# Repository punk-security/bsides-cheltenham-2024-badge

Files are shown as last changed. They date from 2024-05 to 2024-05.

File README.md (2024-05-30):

# bsides-cheltenham-2024-badge
The UFO badge for BSIDES Cheltenham 2024!

Lots of things in this repo:

- eagle-files: all the stuff you need to tinker and modify the PCB
- gerber-files.zip: the file you can upload to JLCPCB and order your own badge, as is
- 3d_printed_case.stl: a cool little push fit case you can print
- bsides-cheltenham-2024-badge.ino: the arduino code that powers the badge, which you can modify and flash via the SAO connector
- ufo.svg: the original vector design for the badge
- morse_code_instructional_booklet.pdf: the flyer we gave out on the day with the codes and instructions

## Bill Of Materials

You can see a parts list on DigiKey [here](https://www.digikey.co.uk/en/mylists/list/Z9CH9C1GM3)

Essentially its:

* ATTINY402 microcontroller 
* Button - any surface mount button fitting the footprint will work
* CR2032 battery clip - surface mount not through hole
* Neopixel 5050 addressable LED - Definitely get the right version of these

## Eagle designs and ordering your own badge

We've uploaded the AutoCAD EAGLE schematic, board design and custom footprints so you can make your own variants!  You will probably have to do some tweaks to get it working as they're not designed to be standalone exports.

We've also uploaded the gerber_files.zip.  Take this to JLCPCB and you can order your own exact copies of the board :)

## Writing and flashing code!

We use [MegaTinyCore](https://github.com/SpenceKonde/megaTinyCore) for the arduino interface for ATTINY4x2 chips.

Dev and flashing is done within the Arduino IDE ( < v2 ) using a jtag2updi interface, as discussed [here](https://github.com/SpenceKonde/AVR-Guidance/blob/master/UPDI/jtag2updi.md)

We use [these little usb sticks](https://amzn.eu/d/c0lx0wG), with a 4.7k resistor soldered between the Tx and Rx lines.  

### Installing MegaTinyCore dependencies

This board package can be installed via the board manager in arduino. The boards manager URL is:

`http://drazzy.com/package_drazzy.com_index.json`

1. File -> Preferences, enter the above URL in "Additional Boards Manager URLs"
2. Tools -> Boards -> Boards Manager...
3. Wait while the list loads (takes longer than one would expect, and refreshes several times).
4. Select "megaTinyCore by Spence Konde" and click "Install". For best results, choose the most recent version.

### Setting up the IDE

1. Open the file **bsides-cheltenham-2024-badge.ino** in arduino
2. Select tools > Board > megaTinyCore > ATtiny412/402/212/202
3. Select tools > Chip > ATtiny402
4. Select tools > Clock > 8Mhz internal *(we get power issues otherwise)*
5. Select tools > Programmer > SerialUPDI SLOW
6. Select tools > Port > ( pick your COM port)

### Flashing firmware
1. Connect the 3v3 pin to 3v on your usb (maybe wedge it in the battery clip)
2. Connect GND to GND
3. Connect UPDI to the RxD port
4. Click Upload button

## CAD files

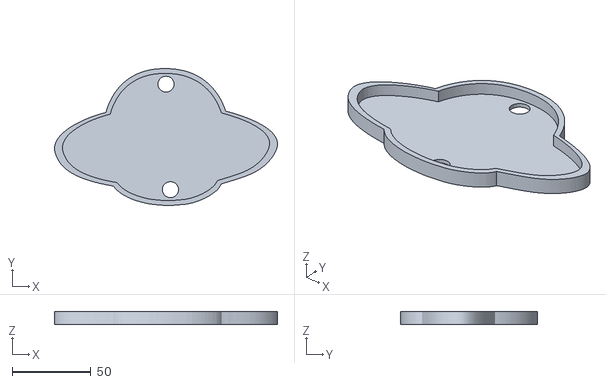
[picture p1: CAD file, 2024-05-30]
3d_printed_case.stl
142.0 x 87.2 x 8.00

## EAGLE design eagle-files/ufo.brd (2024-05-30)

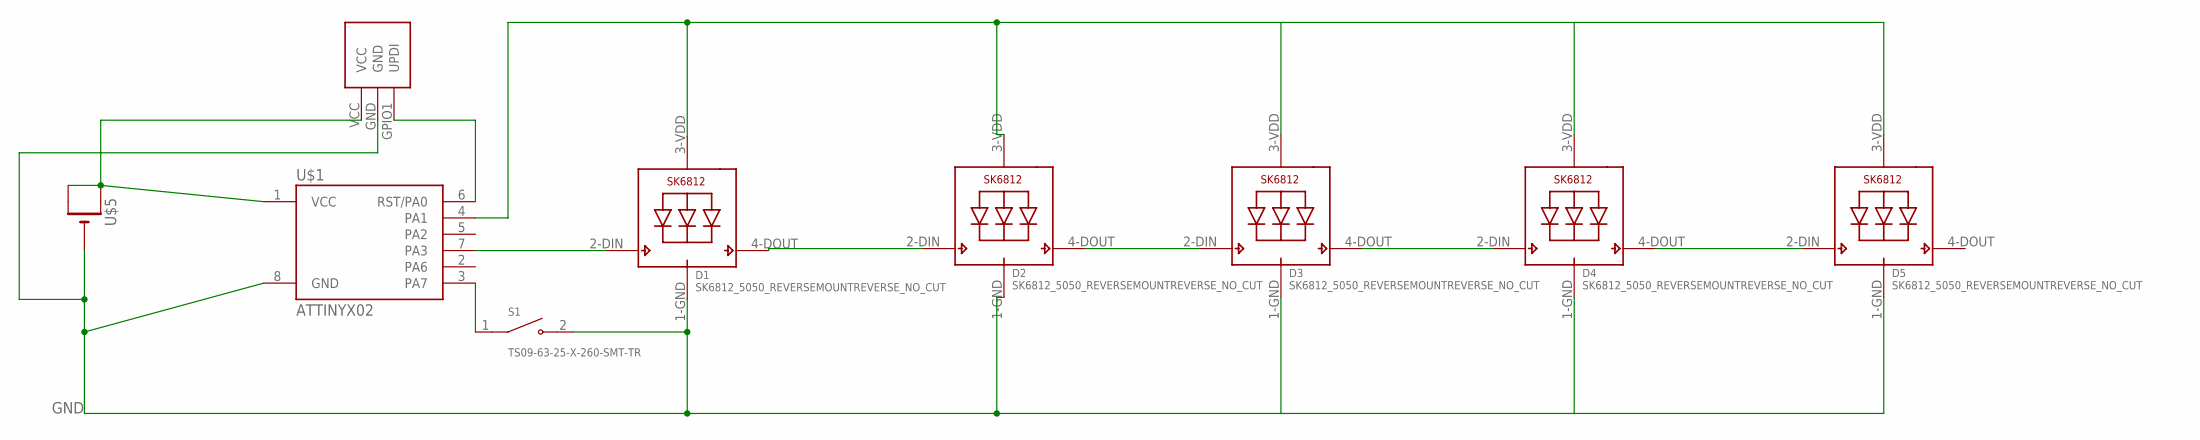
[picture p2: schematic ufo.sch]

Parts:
D1, D2, D3, D4, D5: SK6812_5050_REVERSEMOUNTREVERSE_NO_CUT; SK6812_REVERSE_NO_CUT
S1: TS09-63-25-X-260-SMT-TR; SW_TS09-63-25-X-260-SMT-TR
U$1: ATTINYX02; SOIC08_JEDEC_150MIL
U$2: SAO; SAO_SMD
U$5: CR2032SMT; CR2032-SMD

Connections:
GND: D1.1-GND (GND), D2.1-GND (GND), D3.1-GND (GND), D4.1-GND (GND), D5.1-GND (GND), S1.2, U$1.8 (GND), U$2.GND, U$5.-
unnamed: D1.4-DOUT (DO), D2.2-DIN (DI)
unnamed: D1.2-DIN (DI), U$1.7 (PA3)
unnamed: D3.4-DOUT (DO), D4.2-DIN (DI)
unnamed: D2.4-DOUT (DO), D3.2-DIN (DI)
unnamed: S1.1, U$1.3 (PA7)
unnamed: D4.4-DOUT (DO), D5.2-DIN (DI)
unnamed: U$1.6 (RST/PA0), U$2.GPIO1 (UPDI)
VCC1: U$1.1 (VCC), U$2.VCC, U$5.+$1 (+), U$5.+$2 (+1)
VDD1: D1.3-VDD (VDD), D2.3-VDD (VDD), D3.3-VDD (VDD), D4.3-VDD (VDD), D5.3-VDD (VDD), U$1.4 (PA1)

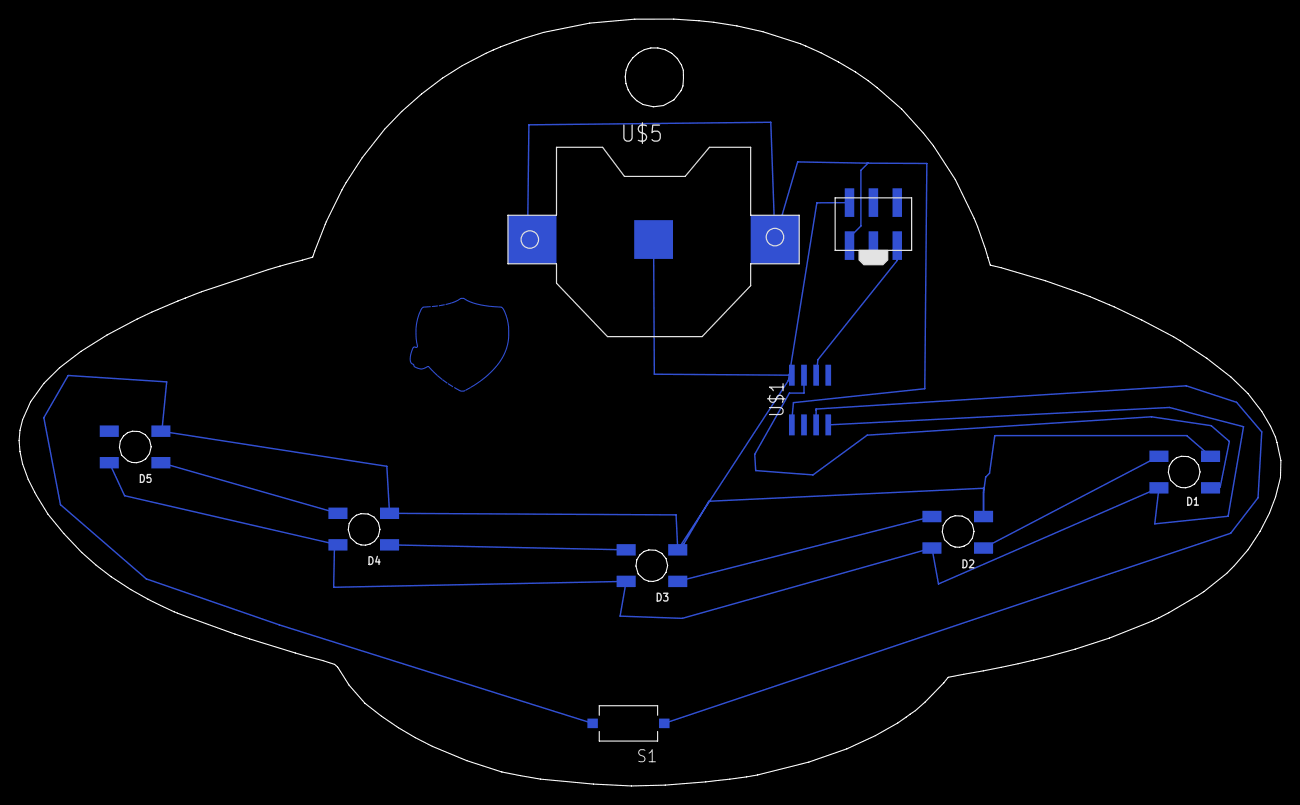
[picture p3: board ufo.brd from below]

Board: 2 copper layers, 132.1 x 80.3 mm, 9 parts (9 on the bottom side), 10 nets.

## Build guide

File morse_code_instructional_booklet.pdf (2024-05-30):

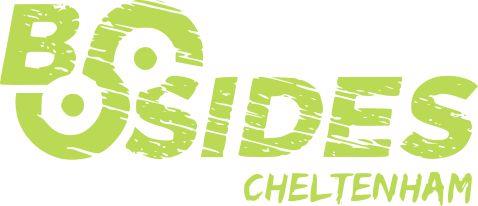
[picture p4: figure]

# Instructions:

⏱️ Short press to change mode
🔐 To unlock a new mode:
> HOLD button until solid blue
> Enter morse code sequence
> Green means good, Red is a fail

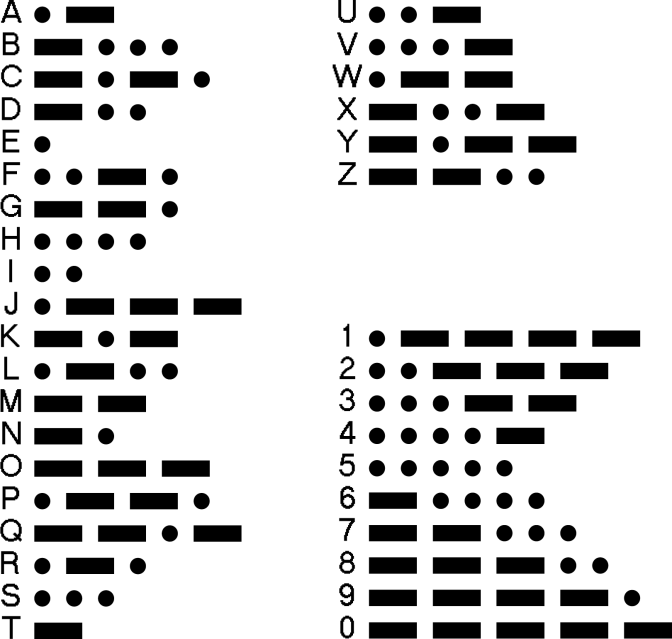
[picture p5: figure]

‼️ TIP: Morse code is time sensitive, leave a small pause between each letter / number.

# Unlock codes:

### > RGB > SOS > 1JUN > UFO > CISO > SEC > PUNK

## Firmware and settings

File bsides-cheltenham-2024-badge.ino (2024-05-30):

#include <avr/io.h>-
#include <avr/pgmspace.h>
#include <avr/sleep.h>
#include <EEPROM.h>
#include <tinyNeoPixel_Static.h>


// PINS
#define MORSE_CODE_PIN PIN_PA7

// COLOURS
#define OFF 0,0,0
#define RED 50,0,0
#define ORANGE 40,10,0
#define YELLOW 30,20,0
#define GREEN 0,50,0
#define BLUE 0,0,50
#define PURPLE 10,0,20
#define PINK 20,0,10



// MORSE CODE
/*
 *
 * MORSE CODE is between 1 and 5 pulses long
 *
 * To store this in one byte we have the length, (3 bits) and each position as either 0 (dot) or 1 (dash)
 * i.e.
 * A = 010 01 000
 * B = 100 1000 0
 * C = 100 1010 0
 */
// A .-
#define m_A B01001000
// B -...
#define m_B B10010000
// C -.-.
#define m_C B10010100
// D -..
#define m_D B01110000
// E .
#define m_E B00100000
// F ..-.
#define m_F B10000100
// G --.
#define m_G B01111000
// H ....
#define m_H B10000000
// I ..
#define m_I B01000000
// J .---
#define m_J B10001110
// K -.-
#define m_K B01110100
// L .-..
#define m_L B10001000
// M --
#define m_M B01011000
// N -.
#define m_N B01010000
// O ---
#define m_O B01111100
// P .--.
#define m_P B10001100
// Q --.-
#define m_Q B10011010
// R .-.
#define m_R B01101000
// S ...
#define m_S B01100000
// T -
#define m_T B00110000
// U ..-
#define m_U B01100100
// V ...-
#define m_V B10000010
// W .--
#define m_W B01101100
// X -..-
#define m_X B10010010
// Y -.--
#define m_Y B10010110
// Z --..
#define m_Z B10011000
// 1 .----
#define m_1 B10101111
// 2 ..---
#define m_2 B10100111
// 3 ...--
#define m_3 B10100011
// 4 ....-
#define m_4 B10100001
// 5 .....
#define m_5 B10100000
// 6 -....
#define m_6 B10110000
// 7 --...
#define m_7 B10111000
// 8 ---..
#define m_8 B10111100
// 9 ----.
#define m_9 B10111110
// 0 -----
#define m_0 B10111111


// MORSE Code timing intervals

#define MORSE_CODE_MAX_DOT_MS 400 // LOW - Any longer than this and its a dash
#define MORCE_CODE_MAX_DASH_MS 2000 // LOW - Any longer than this and its an error
#define MORSE_CODE_MAX_CHAR_INTERVAL_MS 800 // LOW - Any longer than this and we end the character
#define MORSE_CODE_MAX_WORD_INTERVAL_MS MORSE_CODE_MAX_CHAR_INTERVAL_MS * 2 // LOW - Any longer than this and we end the secret code
#define MORSE_CODE_MAX_HIGH_MS MORCE_CODE_MAX_DASH_MS

#define MORSE_CODE_CHAR_ERROR 0
#define MAX_SECRET_CODE_LENGTH 4
#define NUMLEDS 5
#define WAKE_TIME_MS 300000

uint16_t time_pin_low(uint16_t max_ms)
{
  // blocking for up to max_ms
  if (digitalRead(MORSE_CODE_PIN) == HIGH)
  {
    return(0);
  }
  delay(50); //debounce-
  uint16_t t = 50;
  while(digitalRead(MORSE_CODE_PIN) == LOW)
  {
    delay(5);
    t = t + 5;
    if ( t > max_ms )
      return(max_ms);
  }
  return(t);
}

uint16_t time_pin_high(uint16_t max_ms)
{
  // blocking for up to max_ms
  if (digitalRead(MORSE_CODE_PIN) == LOW)
  {
    return(0);
  }
  delay(50); //debounce-
  uint16_t t = 50;
  while(digitalRead(MORSE_CODE_PIN) == HIGH)
  {
    delay(5);
    t = t + 5;
    if ( t > max_ms )
      return(max_ms);
  }
  return(t);
}

byte read_morse_char()
{
  // this function blocks
  byte code = B0000000;
  uint16_t lastPulseLength;
  uint8_t pos = 0;
  while(pos < 5)
  {
    lastPulseLength = time_pin_low(MORCE_CODE_MAX_DASH_MS);
    if (lastPulseLength == 0 || lastPulseLength == MORCE_CODE_MAX_DASH_MS) {return MORSE_CODE_CHAR_ERROR;} // return null byte on error
    if (lastPulseLength < MORSE_CODE_MAX_DOT_MS)
    {
      // set dot as the LOW was less than a dash
      // dots are zero so nothing to set but bump the pos
      pos++;
    }
    else
    {
      // set dash
      bitSet(code, (4 - pos)); // bits in byte are 76543210, we start at 4 and move right
      pos++;
    }
    // At this point we have read the low dash or dot but we dont know if its the end of the char.
    lastPulseLength = time_pin_high(MORSE_CODE_MAX_CHAR_INTERVAL_MS);
    if (lastPulseLength == MORSE_CODE_MAX_CHAR_INTERVAL_MS)
    {
      // The low time was higher than the intra-character spacing max so must end this character
     code |= pos << 5; // set the pos bits
     return(code); 
    }
  }
    // We have already got all 5 dots/dashes, cant RX any more
    return MORSE_CODE_CHAR_ERROR; //return Error
}

void read_morse_word(char code[])
{
  uint8_t pos = 0;
  pos = 0;
  byte lastChar;
  int8_t lastPulseLength;
  while(pos < MAX_SECRET_CODE_LENGTH)
  {
    lastChar = read_morse_char();
    if (lastChar == MORSE_CODE_CHAR_ERROR)
      return "";
    // We should still be HIGH here - we left the function because the wait was longer than the intra char interval
    code[pos] = lastChar;
    pos++;
    // Should we end the string early or capture the next character?
    if (time_pin_high(MORSE_CODE_MAX_WORD_INTERVAL_MS) == MORSE_CODE_MAX_WORD_INTERVAL_MS)
    {
      // The char interval has already passed inside the read_morse_char func.
      // If we go that length AGAIN twice, the code is over
      // i.e.  CHAR INT = 1s, WORD INT = 2s, 1s has elapsed so wait up to 1s for the next LOW to start
      return;
    }
  }
  // At MAX code length, so return
  return;
}

byte pixels[NUMLEDS * 3];
tinyNeoPixel strip = tinyNeoPixel(NUMLEDS, PIN_PA3, NEO_GRB, pixels);

void setAllPixels(int r, int g, int b, bool show = false)
{
  for (int i = 0; i < NUMLEDS; i++) 
  {
    strip.setPixelColor(i,r,g,b);
  }
  if(show)
    strip.show();
}

int police(int x)
{
  if( x % 2 == 0)
  {
    strip.setPixelColor(0,RED);
    strip.setPixelColor(1,BLUE);
    strip.setPixelColor(2,RED);
    strip.setPixelColor(3,BLUE);
    strip.setPixelColor(4,RED);
  }
  else
  {
    strip.setPixelColor(0,BLUE);
    strip.setPixelColor(1,RED);
    strip.setPixelColor(2,BLUE);
    strip.setPixelColor(3,RED);
    strip.setPixelColor(4,BLUE);
  }
  strip.show();
  return 200;
}

int fill(int x, int r, int g, int b)
{
  int step = x % 10;
  switch(step)
  {
    case 0:
      setAllPixels(OFF);
      break;
    case 1 ... 6:
      strip.setPixelColor(step - 1, r,g,b);
      break;
    default:
      break;
  }
  strip.show();
  return 100;
}

void sleep()
{
  set_sleep_mode(SLEEP_MODE_PWR_DOWN);
  PORTA.PIN7CTRL = PORT_PULLUPEN_bm | PORT_ISC_LEVEL_gc; // enable pullup and interrupt
  digitalWrite(PIN_PA1, LOW); // turn off LED power rail
  sleep_enable();
  sleep_cpu();
  // sleep resumes here
  PORTA.PIN7CTRL = PORT_PULLUPEN_bm; // renable pullup but no interrupt
  digitalWrite(PIN_PA1, HIGH);  // turn on LED power rail
}

ISR(PORTA_PORT_vect) {
  PORTA.INTFLAGS = PORT_INT7_bm; // Clear Pin 7 interrupt flag otherwise keep coming back here
}

uint8_t state;

void setup()
{
  // Power save
  // http://www.technoblogy.com/show?2RA3
  // https://github.com/SpenceKonde/megaTinyCore/blob/master/megaavr/extras/PowerSave.md
  ADC0.CTRLA &= ~ADC_ENABLE_bm; // Disable ADC
  pinMode(PIN_PA1, OUTPUT);
  pinMode(PIN_PA2, OUTPUT);
  pinMode(PIN_PA3, OUTPUT);
  pinMode(PIN_PA6, OUTPUT);
  // UPDI does not need setting (PA0)

  // Pin setup
  pinMode(PIN_PA7, INPUT_PULLUP);
  digitalWrite(PIN_PA1, HIGH);

  // Read eeprom to state
  state = EEPROM.read(0);
  if (state == B11111111)
  {
    EEPROM.update(0, 0);
    state = EEPROM.read(0);
  }
  // state = B11111111; // Comment out before flash
  
}

bool c_array(char array_1[],char array_2[])
{
  for (int i = 0;  i < MAX_SECRET_CODE_LENGTH; i++)
  {
  if( array_1[i] != array_2[i] ) 
    return false;
  }
  return true;
}

void success()
{
    EEPROM.update(0, state);
    setAllPixels(0,5,0,true);
    delay(500);
}

void fail()
{
    setAllPixels(5,0,0,true);
    delay(500);
}

void c_morse()
{
  // SECRET CODES
  char secret1[MAX_SECRET_CODE_LENGTH] = {m_R, m_G, m_B, 0}; //STROBE
  char secret2[MAX_SECRET_CODE_LENGTH] = {m_S, m_O, m_S, 0}; //POLICE
  char secret3[MAX_SECRET_CODE_LENGTH] = {m_1, m_J, m_U, m_N};  //VEGAS
  char secret4[MAX_SECRET_CODE_LENGTH] = {m_C, m_I, m_S, m_O}; //RED
  char secret5[MAX_SECRET_CODE_LENGTH] = {m_U, m_F, m_O, 0};  // BLUE
  char secret6[MAX_SECRET_CODE_LENGTH] = {m_S, m_E, m_C, 0}; // YELLOW
  char secret7[MAX_SECRET_CODE_LENGTH] = {m_P, m_U, m_N, m_K}; // PUNK
  char secret_reset[MAX_SECRET_CODE_LENGTH] = {m_R, m_S, m_T, 0};
  char secret_all[MAX_SECRET_CODE_LENGTH] = {m_1, m_3, m_3, m_7};
  // BUFFER TO READ TO
  char i[MAX_SECRET_CODE_LENGTH] = {0};
  // SET PIXELS TO SHOW WE ARE READIING
  setAllPixels(0,0,5,true);
  // READ INPUT
  while(digitalRead(MORSE_CODE_PIN) == LOW)
    delay(10);
  while(digitalRead(MORSE_CODE_PIN) == HIGH)
    delay(10);
  read_morse_word(i);
  //flash_morse_word(i);
  // TEST FOR A MATCH
  if (c_array(i, secret1))
  {
    state = state | B00000001;
    return success();
  }
  if (c_array(i, secret2))
  {
    state = state | B00000010;
    return success();
  }
  if (c_array(i, secret3))
  {
    state = state | B00000100;
    return success();
  }
  if (c_array(i, secret4))
  {
    state = state | B00001000;
    return success();
  }
  if (c_array(i, secret5))
  {
    state = state | B00010000;
    return success();
  }
  if (c_array(i, secret6))
  {
    state = state | B00100000;
    return success();
  }
  if (c_array(i, secret7))
  {
    state = state | B01000000;
    return success();
  }
  if (c_array(i, secret_reset))
  {
    state = B0;
    return success();
  }
  if (c_array(i, secret_all))
  {
    state = B11111111;
    return success();
  }
  return fail();
}

int vegas(int x)
{
  setAllPixels(0,0,0);
  if (x % 2)
  {
    strip.setPixelColor(0,YELLOW);
    strip.setPixelColor(2,YELLOW);
    strip.setPixelColor(4,YELLOW);
  }
  else
  {
    strip.setPixelColor(1,YELLOW);
    strip.setPixelColor(3,YELLOW);
  }
  strip.show();
  return 300;
}

int loading(int x)
{
  int i = x % 25;
  if ( i < 5 )
  {
    setAllPixels(0,0,0);
    strip.setPixelColor(i,RED);
    strip.show();
  }
  else if ( i < 9 )
  {
    setAllPixels(0,0,0);
    strip.setPixelColor(4,RED);
    strip.setPixelColor(i-6,ORANGE);
    strip.show();
  }
  else if ( i < 13 )
  {
    setAllPixels(0,0,0);
    strip.setPixelColor(4,RED);
    strip.setPixelColor(3,ORANGE);
    strip.setPixelColor(i-11,YELLOW);
    strip.show();
  }
  else if ( i < 16 )
  {
    setAllPixels(0,0,0);
    strip.setPixelColor(4,RED);
    strip.setPixelColor(3,ORANGE);
    strip.setPixelColor(2,YELLOW);
    strip.setPixelColor(i-15,GREEN);
    strip.show();
  }
  else if ( i < 18 )
  {
    setAllPixels(0,0,0);
    strip.setPixelColor(4,RED);
    strip.setPixelColor(3,ORANGE);
    strip.setPixelColor(2,YELLOW);
    strip.setPixelColor(1,GREEN);
    strip.setPixelColor(0,BLUE);
    strip.show();
  }
  return (100 + (i * 10));
}

int cycle(int n)
{
  int i = n % 6;
  switch(i) {
   case 0:
    setAllPixels(RED,true);
    break;
   case 1:
    setAllPixels(ORANGE,true);
    break;
   case 2:
    setAllPixels(YELLOW,true);
    break;
   case 3:
    setAllPixels(GREEN,true);
    break;
   case 4:
    setAllPixels(BLUE,true);
    break;
   case 5:
    setAllPixels(PURPLE,true);
    break;
  }
  return 200;
}

int fill_cycle(int x)
{
  int color_step = x % 60;
  switch (color_step)
  {
    case 1 ... 9:
      return fill(color_step,RED);    
    case 11 ... 19:
      return fill(color_step,ORANGE);
    case 21 ... 29:
      return fill(color_step,YELLOW);
    case 31 ... 39:
      return fill(color_step,GREEN);
    case 41 ... 49:
      return fill(color_step,BLUE);    
    case 51 ... 59:
      return fill(color_step,PURPLE);
  }
  return 0;
}

int knightrider(int i, int r, int g, int b)
{
  int n = i % 9;
  setAllPixels(OFF);
  if (n > 4)
  {
    n = 4 - (n - 5);
  }
  if (n == 2)
  {
    r = r * 4;
    g = g * 4;
    b = b * 4;
  }
  strip.setPixelColor(n,r,g,b);
  strip.show();
  return 100;
}

void loop()
{
  int mode = 0;
  int interval;
  uint16_t button_low_time = 0;
  uint32_t total_interval = 0;
  strip.begin();
  int i = 0;
  while(true)
  {
    if ( mode == 0 )
    {
      interval = vegas(i);
    }
    else if ( mode == 1 && (state & B00000001 ))
    {
      interval = cycle(i);
    }
    else if ( mode == 2 && (state & B00000010 ))
    {
      interval = police(i);
    }
    else if ( mode == 3 && (state & B00000100 ))
    {
      interval = loading(i);
    }
    else if ( mode == 4 && (state & B00001000 ))
    {
      interval = knightrider(i,20,0,0);
    }
    else if ( mode == 5 && (state & B00010000 ))
    {
      interval = fill(i,0,0,255);
    }
    else if ( mode == 6 && (state & B00100000 ))
    {
      interval = fill(i,30,50,0);
    }
    else if ( mode == 7 && (state & B01000000 ))
    {
      interval = fill_cycle(i);
    }
    else
    {
      mode = (mode +1) % 8;
      continue;
    }
    i++;
    // This section breaks down the sleep interval to catch button presses
    total_interval = total_interval + interval;
    while(interval > 0)
    {
      delay(10);
      interval = interval - 10;
      button_low_time = time_pin_low(2000);
      if (button_low_time > 200)
      {
       /*
       * MAIN MENU
       * NO PRESS = CONTINUE
       * SHORT PRESS = CHANGE FLASHY MODE
       * LONG PRESS = ENTER MORSE CODE MODE
       */
        if (button_low_time > 1200)
        {
          c_morse();
        }
        else
        {
          mode = (mode +1) % 8;
        }
        // reset timer
        i = 0;
        total_interval = 0;
      }

    }
    // At the end of each interval, see if we need to sleep
    if (total_interval > WAKE_TIME_MS)
    {
      total_interval = 0;
      i = 0;
      sleep();
    }
  }
}
